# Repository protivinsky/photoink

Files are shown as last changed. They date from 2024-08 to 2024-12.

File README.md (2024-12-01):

# DIY E-Ink Photo Frame

This repository shows how to turn color e-ink display into a personal digital photo frame and provide all the necessary code. The final result is shown below, the frame will randomly cycle about ten photos of your selection. E-ink displays still have some limitations, so the visual quality is not stellar (low pixel resolution and small set of colors that can be displayed), however it is a nice and relatively inexpensive DIY project (around 100 USD total). With a small battery, the frame will run even several months on a single charge. All the components can be bought on Aliexpress or from another sellers and everything can be put together in a few hours. All code is just in python.

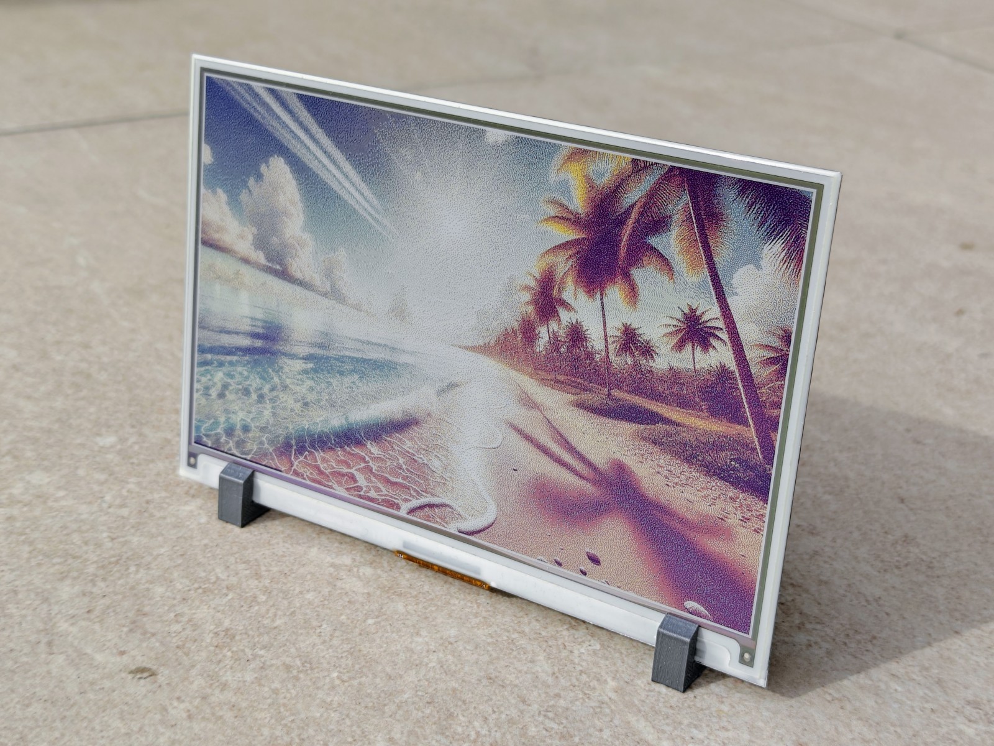
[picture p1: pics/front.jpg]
Front side

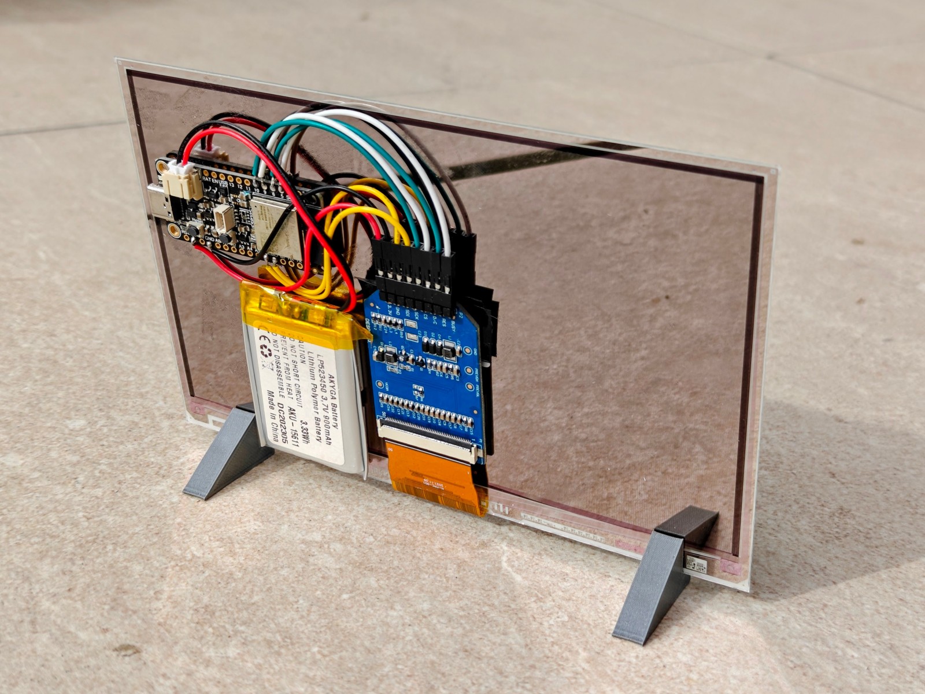
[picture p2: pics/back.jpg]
Back side


## Components

### Display

You need 7.3 inch full color e-ink display:

- [Good Display GDEY073D46](https://www.good-display.com/product/442.html) - older ACeP version, supporting 7 colors, might not be in stock anymore. [AliExpress](https://www.aliexpress.com/item/1005005671413173.html), [Laskakit](https://www.laskakit.cz/good-display-gdey073d46-7-3--800x480-epaper-barevny-displej/) (local Czech seller I typically use)
  - Update 2024-12-01: [Waveshare](https://www.waveshare.com/7.3inch-e-paper-f.htm) also offers this ACeP display. I prefer it over the newer and faster Spectre E6, the orange color means the photos look less noisy and I do not mind slower refresh rate on the photo frame.
- [Good Display GDEP073E01](https://www.good-display.com/product/533.html) - newer Spectra E6 version, faster refresh, but support only 6 colors. [AliExpress](https://www.aliexpress.com/item/1005007253583430.html), [Laskakit](https://www.laskakit.cz/good-display-gdep073e01-7-3--800x480-epaper-barevny-displej/).

In addition, you need a connection adapter board that handles the serial communication between the display and microcontroller:
- [Epaper HAT Connection Adapter Board](https://www.buyepaper.com/products/epaper-hat-connection-adapter-board-for-073-inch-e-ink-display-despi-c73-648) - it is identical for both displays. [AliExpress](https://www.aliexpress.com/item/1005005671328036.html), [Laskakit](https://www.laskakit.cz/good-display-despi-c73-univerzalni-spi-e-paper-adapter/)

Both displays are very similar and almost identical code works for both of them. They are very thin (sub 1mm), so it adds to photo-like feel. The picture above features GDEY073D46 (the older ACeP version, Advanced Color ePaper) - it has resolution 800x480 pixels and can display black, white, yellow, orange, red, green and blue colors. The newer GDEP073E01 has the same resolution, cannot display orange (so images look slightly less warm - tbh I slightly prefer the older look, especially for faces, but the difference is really small) and it has much faster refresh (it takes about half a minute of blinking to change an image on the older version, compared to about 10 seconds on the newer one). The faster refresh might mean also much longer battery life (as the power is needed only when refreshing and switching the images), but I did not compare this directly.

### Controller

I used [Adafruit Feather ESP32-S3](https://www.adafruit.com/product/5477) (product id 5477). Many others can be likely used as well, this one has several nice features:
- Good support for CircuitPython
- USB-C for flashing and charging
- JST-PH on board for connecting battery (the controller handles the charging)
- The controller can behave as external storage when connected to computer - photos can be copied easily

[AliExpress](https://www.aliexpress.com/item/1005007532295735.html), [Botland CZ](https://botland.cz/desky-kompatibilni-s-arduino-adafruit/21579-feather-esp32-s3-wifi-gpio-modul-4-mb-flash-2-mb-psram-kompatibilni-s-arduino-adafruit-5477.html)

### Battery

Any battery with 3.7V and JST-PH connector should work. I used LiPol battery with 900 mAh and it lasted for 2-3 months on a single charge with changing the images every 2 hours. The battery is the heaviest component, you can also opt for the smaller 500 mAh one.

- LiPol battery 603048 900mAh 3.7V - [AliExpress](https://www.aliexpress.com/item/32921358236.html), [Laskakit](https://www.laskakit.cz/ehao-lipol-baterie-603048-900mah-3-7v/)

### Standing feet

3D printed, based on the [standing_feet.scad](standing_feet.scad) OpenSCAD file.

### Others

Some jumper wires with female connector on one end (commonly used with breadboard) and the soldering equipment. It is very easy soldering, I had basically no experience with it before - only needed to connect the other end of wires to the controller. Alternatively you can use controller with headers and just connect everything with female-female wires, without any soldering at all (but you might not be able to attach everything to the back of the frame).

## Tutorial

1. Preparing photos
2. Connecting the controller and the display
3. Flashing the code to the controller
4. Optionally, printing the standing feet

### 1. Preparing photos

As the resolution is only 800x480 and the display can use only a limited set of colors, all photos has to be cropped, resized and converted to an appopriate color palette. All of this is handled by [prepare_photos.py](prepare_photos.py) Intended to run with normal Python 3 on computer, `pyproject.toml` contains the dependencies for poetry. The script processes all photos stored under `photos` folder and saves the transformed photos in `ready` folder. The display uses 4 bits for every pixel (to directly encode six or seven colors). It is a bit wasteful, as only 3 bits should be actually needed - but it allows to store 2 pixels in every byte, so it is more convenient to work with. I do not use any compression, so every transformed photo is exactly 400 x 480 = 192 000 bytes, so you can store 10 of them on the controller. The transformed photos have the same names as the originals and use `.bin` suffix, as they just store the images in their binary representation directly.

After connecting the controller to the computer, it should appear as a storage device (after pressing `reset` button on the controller) and the photos should be just copied there under `img` folder.

**If you have the newer GDEP073E01 display, use [spectra/prepare_photos.py](spectra/prepare_photos.py) instead!** It does not use orange color and encode other colors slightly differently, so the transformation of the photos has to be modified.

### 2. Connecting controller and display

Adapter board has 8 pins that need to be connected to corresponding pins on the controller by wires:

- 3.3V and GND should be connected to 3V and GND on the controller
- SDI and SCK to pins for SPI interface on the controller: SCK should be directly there, SDI correspond to MOSI (or just MO on small controllers)
- the rest - CS (chip select), D/C (data / command), RES (reset), BUSY - to any digital pins. I used 10, 9, 6 and 5 respectively (the exact pins are defined in the code for the controller).

I just cut the wire, removed a part of the plastic and soldered it directly to appropriate pins. Connecting the battery to the controller and the display to the adapter board is straightforward. I attached everything to the back of the display with thick two-sided tape (intended for bathroom tiles originally).

### 3. Code for the controller

Everything is stored under the folder `controller`. The `lib` subfolder contains required libraries for SPI serial communication and for checking the battery state for this particular controller, all is available on the internet.

The Adafruit 5477 controller can be programmed with [CircuitPython](https://circuitpython.org) and [Thonny](https://thonny.org) is a very convenient IDE to use for it. It can directly flash the controller with CircuitPython and then run the code on the controller, even with REPL. So after flashing CircuitPython, the content of the folder `controller` should be just copied into the controller.

All the custom code is in [controller/code.py](controller/code.py) file and mo of it is direct translation of original C++ code provided by the manufacturer (the initialization sequences). Then the controller checks all files within `img` subfolder, selects one of them at random and sends it to the controller. In addition, the state of the battery is checked and it is shown at the bottom of the frame as black line ("no black line" = battery is full; "black line over the whole lenght of the frame" = battery is empty). The battery status is only appoximate, but I still find it useful and inobtrusive.

After displaying the picture, the controller goes to sleep and wakes up again in 1 hour to display another picture. As the display does not require any power for showing the picture, only for changing them, the battery can last for weeks and months.

**If you have the newer GDEP073E01 display, it is better to use [spectra/code.py](spectra/code.py) instead of the version in `controller` folder.** There is one small recommended change in the initalization sequence (however it does not seem to be necessary).

### 4. Standing feet

They are defined with open-source [OpenSCAD](https://openscad.org) 3D modeller in [standing_feet.scad](standing_feet.scad) file. You can just export them for 3D printing and then continue according to 3D printer that you have available. I used OpenSCAD as it allowed all the modelling to be handled in code and my requirements were very simple.

And that's it, enjoy!

## Further ideas

### Raspberry Pi

The display can be also control similarly from Raspberry Pi, only the code for setting up the pins and SPI communication has to be modified accordingly. The display can be them controlled even interactively via REPL.

### Bigger display

I was considering also bigger [13.3 inch GDEP133C02 display](https://www.good-display.com/product/559.html). It has better resolution (even though similar dpi). However it is much more expensive and at the moment, it can be used only with Good Display development board and there is no sample code (it relies fully on executable provided by Good Display).

I do not know about any similar display kit that would allow to show more colors or provide better resolution.

### Code tweaks and improvement

Another possible improvements that I was considering, but was not really worthy for my use case:
- Use compression for storing images (not sure what is supported on CircuitPython).
- Use different conversion between RGB and 6/7-color palettes. Currently the conversion tries to preserve colors, however the result might be quite pixelated for some input images. Maybe this can be tweak to have less larger areas of identical color, even if it is less well matching the original.

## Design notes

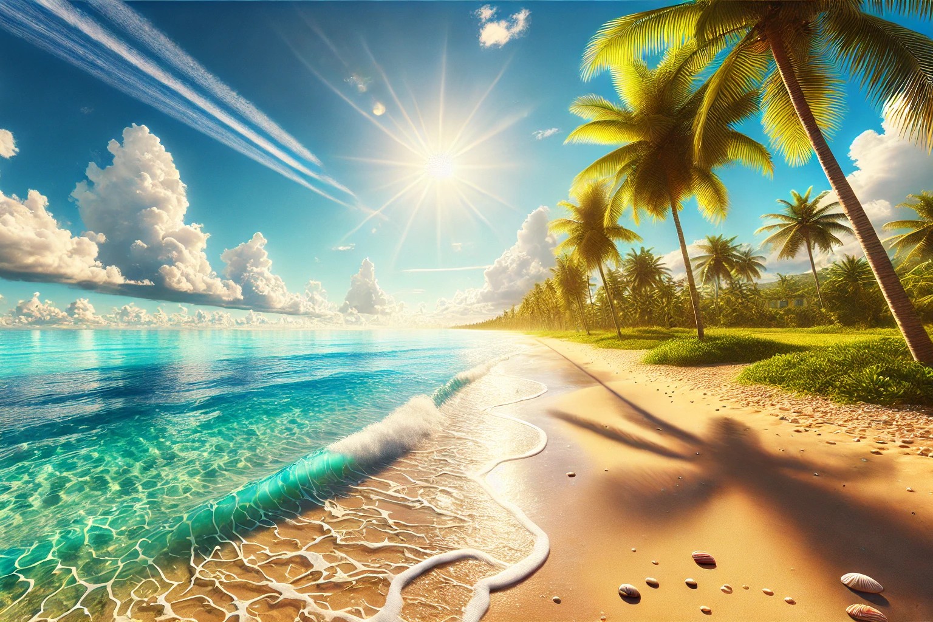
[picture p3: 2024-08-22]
photos/beach.jpg

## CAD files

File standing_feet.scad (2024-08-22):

// Define the triangle points
A = [0, 0];
B = [3.2, 0];
// C = [0.2102, 2];
// D = [0.6102, 1.732];
C = [0.1366, 1.3];
D = [0.582, 1.5];
E = [0.7602, 1.632];
F = [0.4526, 0.5];
G = [0.626, 0.5];

points = [A, B, E, G, F, D, C];

// Function to create the scaled and extruded object
module createObject() {
    scale([10, 10, 10])
    linear_extrude(height = 0.8)  // Ensure height is also scaled
        polygon(points);
}

// Create the first object
createObject();

// Create the second object with an offset
translate([0, 25, 0]) // Adjust the X offset as needed
    createObject();

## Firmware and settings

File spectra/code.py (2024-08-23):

import os
import random
import time
import alarm
import busio
import board
import digitalio
import adafruit_max1704x


# Initialize SPI
spi = busio.SPI(board.SCK, MOSI=board.MOSI, MISO=board.MISO)
while not spi.try_lock():
    pass
spi.configure(baudrate=1000000)


# Setup the pins
PIN_DC = digitalio.DigitalInOut(board.D9)
PIN_DC.direction = digitalio.Direction.OUTPUT
PIN_RES = digitalio.DigitalInOut(board.D6)
PIN_RES.direction = digitalio.Direction.OUTPUT
PIN_CS = digitalio.DigitalInOut(board.D10)
PIN_CS.direction = digitalio.Direction.OUTPUT
PIN_BUSY = digitalio.DigitalInOut(board.D5)
PIN_BUSY.direction = digitalio.Direction.INPUT


# Color definitions for the GDEP073E01 Spectra E6 display
# 8bit
Black = 0x00    # 000
White = 0x11    # 001
Yellow = 0x22   # 010
Red = 0x33      # 011
Blue = 0x55     # 101
Green = 0x66    # 110
Clean = 0x77    # 111

# 4bit
black = 0x00    # 000
white = 0x01    # 001
yellow = 0x02   # 010
red = 0x03      # 011
blue = 0x05     # 101
green = 0x06   # 110
clean = 0x07    # 111

# control vars
PSR = 0x00
PWRR = 0x01
POF = 0x02
POFS = 0x03
PON = 0x04
BTST1 = 0x05
BTST2 = 0x06
DSLP = 0x07
BTST3 = 0x08
DTM = 0x10
DRF = 0x12
PLL = 0x30
CDI = 0x50
TCON = 0x60
TRES = 0x61
REV = 0x70
VDCS = 0x82
T_VDCS = 0x84
PWS = 0xE3


def set_pin(pin, value):
    pin.value = value


# Not really needed
def set_cs(value):
    pass
    # set_pin(PIN_CS, value)


EPD_W21_RST_0 = lambda: set_pin(PIN_RES, False)
EPD_W21_RST_1 = lambda: set_pin(PIN_RES, True)
EPD_W21_DC_0 = lambda: set_pin(PIN_DC, False)
EPD_W21_DC_1 = lambda: set_pin(PIN_DC, True)


def wait_for_display():
    """ Wait till the display is ready """
    while (not PIN_BUSY.value):
        ...

def write_cmd(command):
    """ Send command to the display """
    set_cs(False)
    PIN_DC.value = False
    spi.write(bytes([command]))
    set_cs(True)


def write_data(data):
    """ Send data to the display """
    set_cs(False)
    PIN_DC.value = True
    data = data if isinstance(data, list) else [data]
    spi.write(bytes(data))
    set_cs(True)


def init():
    set_cs(False)
    PIN_RES.value = False
    time.sleep(0.01)
    PIN_RES.value = True
    time.sleep(0.01)
    set_cs(True)


def display_init():
    """
    Full display initialization sequence as provided by the manufacturer.
    https://www.good-display.com/product/442.html (under "Download" in Sample codes)
    """
    init()
    write_cmd(0xaa)
    write_data([0x49, 0x55, 0x20, 0x08, 0x09, 0x18])
    write_cmd(PWRR)
    write_data([0x3F, 0x00, 0x32, 0x2A, 0x0E, 0x2A])
    write_cmd(PSR)
    write_data([0x5F, 0x69])
    write_cmd(POFS)
    write_data([0x00, 0x54, 0x00, 0x44])
    write_cmd(BTST1)
    write_data([0x40, 0x1F, 0x1F, 0x2C])
    write_cmd(BTST2)
    write_data([0x6F, 0x1F, 0x16, 0x25])
    write_cmd(BTST3)
    write_data([0x6F, 0x1F, 0x1F, 0x22])
    write_cmd(0x13)  # IPC
    write_data([0x00, 0x04])
    write_cmd(PLL)
    write_data(0x02)
    write_cmd(0x41)  # TSE
    write_data(0x00)
    write_cmd(CDI)
    write_data(0x3F)
    write_cmd(TCON)
    write_data([0x02, 0x00])
    write_cmd(TRES)
    write_data([0x03, 0x20, 0x01, 0xE0])
    write_cmd(VDCS)
    write_data(0x1E)
    write_cmd(T_VDCS)
    write_data(0x01)
    write_cmd(0x86)  # AGID
    write_data(0x00)
    write_cmd(PWS)
    write_data(0x2F)
    write_cmd(0xE0)  # CCSET
    write_data(0x00)
    write_cmd(0xE6)  # TSSET
    write_data(0x00)
    write_cmd(0x04)  # PWR ON
    time.sleep(0.1)
    wait_for_display()


def acep_color(color):
    """ Display a single 8-bit color on the display """
    write_cmd(0x10)
    for i in range(480):
        for _ in range(400):
            write_data(color)
    write_cmd(0x12)
    write_data(0x00)
    time.sleep(0.001)
    wait_for_display()


def display_sleep():
    """ Put the display to sleep """
    write_cmd(0x02)
    write_data(0x00)
    wait_for_display()


def load_image_data(path):
    """ Load image data from a file """
    with open(path, 'rb') as f:
        image_data = f.read()
    return image_data


def write_bytes(bytes_data):
    """ Send bytes to the display """
    set_cs(False)
    PIN_DC.value = True
    spi.write(bytes_data)
    set_cs(True)


def show_image_data(image_data):
    """ Display the image data on the display """
    write_cmd(0x10)
    write_bytes(image_data)
    write_cmd(0x12)
    write_data(0x00)
    time.sleep(0.001)
    wait_for_display()


if __name__ == '__main__':

    folder = 'img'
    # For how long should the display sleep before changing to the next image
    sleep_time = 3600

    files = os.listdir(folder)
    file = random.choice(files)

    # Check the battery level
    monitor = adafruit_max1704x.MAX17048(board.I2C())
    time.sleep(0.1)
    cell_percent = max(min(monitor.cell_percent, 100.0), 0.0)

    display_init()
    image_data = load_image_data(f'{folder}/{file}')

    # Modify the image data to show the battery level
    battery_data_width = 400 - round(4 * cell_percent)
    battery_data = bytes([0x00] * battery_data_width)
    image_data = (image_data[:-1200] +
                battery_data + image_data[-1200 + battery_data_width:-800] +
                battery_data + image_data[-800 + battery_data_width:-400] +
                battery_data + image_data[-400 + battery_data_width:])

    show_image_data(image_data)
    display_sleep()

    # Sleep for `sleep_time`, then wake up and repeat the script
    time_alarm = alarm.time.TimeAlarm(monotonic_time=time.monotonic() + sleep_time)
    alarm.exit_and_deep_sleep_until_alarms(time_alarm)

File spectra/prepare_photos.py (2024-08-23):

import os
from PIL import Image
import numpy as np


# 6-color palette for GDEP073E01 Spectra E6 display
palette = [
    (0, 0, 0),       # Black
    (255, 255, 255), # White
    (255, 255, 0),   # Yellow
    (255, 0, 0),     # Red
    (0, 0, 255),     # Blue
    (0, 255, 0),     # Green
]


def resize_and_truncate(image, target_size=(800, 480)):
    """Resize the image to fit the target size and truncate symmetrically"""
    # Calculate the aspect ratio
    aspect_ratio = image.width / image.height
    target_aspect_ratio = target_size[0] / target_size[1]

    # Resize the image proportionally
    if aspect_ratio > target_aspect_ratio:
        # Resize by height and then truncate the width symmetrically
        resized_image = image.resize((int(target_size[1] * aspect_ratio), target_size[1]), Image.LANCZOS)
        left_margin = (resized_image.width - target_size[0]) // 2
        right_margin = (resized_image.width - target_size[0] + 1) // 2
        top_margin = 0
        bottom_margin = 0

    else:
        # Resize by width and then truncate the height symmetrically
        resized_image = image.resize((target_size[0], int(target_size[0] / aspect_ratio)), Image.LANCZOS)
        left_margin = 0
        right_margin = 0
        top_margin = (resized_image.height - target_size[1]) // 2
        bottom_margin = (resized_image.height - target_size[1] + 1) // 2

    # Truncate symmetrically from both sides to fit the target size
    truncated_image = resized_image.crop((left_margin, top_margin, resized_image.width - right_margin, resized_image.height - bottom_margin))
    return truncated_image


def get_image_data(file):
    """Resize and convert an image to the 7-color palette and return the image data"""
    image = Image.open(file)
    # image = image.resize((800, 480))
    image = resize_and_truncate(image)
    palette_img = Image.new('P', (1, 1))
    palette_img.putpalette([col for p in palette for col in p] + [0] * (256 - len(palette)) * 3)
    # Convert the image to the custom palette
    image = image.convert('RGB').quantize(palette=palette_img)
    image_data = np.array(image)
    # Number 4 is not used in Spectra, blue and green are 5 and 6
    image_data = np.where(image_data < 4, image_data, image_data + 1)
    return image_data


if __name__ == "__main__":
    source_dir = "photos"
    dest_dir = "ready"
    for filename in os.listdir(source_dir):
        print(f"Processing {filename}")
        image_data = get_image_data(os.path.join(source_dir, filename))
        colors = image_data[:, 1::2] + 16 * image_data[:, ::2]
        byte_seq = colors.tobytes()
        dest_fullname = f'{dest_dir}/{filename.split(".")[0]}.bin'
        with open(dest_fullname, 'wb') as f:
            f.write(byte_seq)

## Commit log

2024-08-22 first commit with the project
    [stand_3d_model.scad]
2024-08-23 rename standing feet file
    [standing_feet.scad]
